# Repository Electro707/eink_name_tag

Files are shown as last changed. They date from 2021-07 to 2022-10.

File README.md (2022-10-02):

# E-Ink Name Tab Project, by Electro707

This project is for a E-Ink name-tag, meant to be the cooler replacement for a paper name-tag for event and shows.

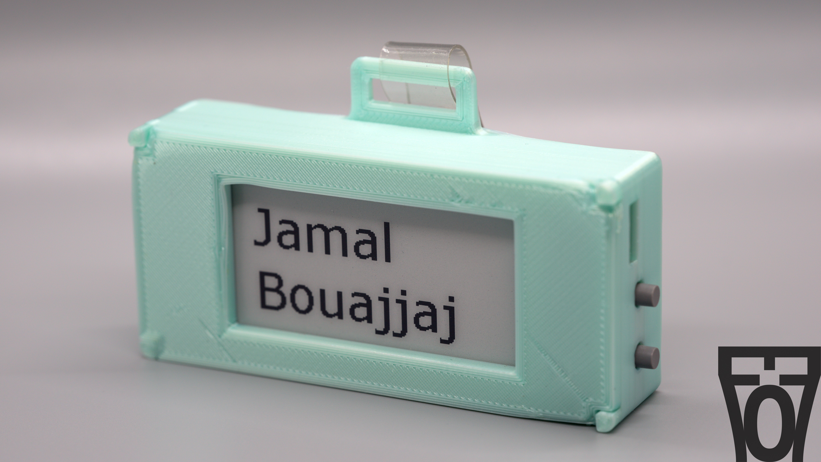
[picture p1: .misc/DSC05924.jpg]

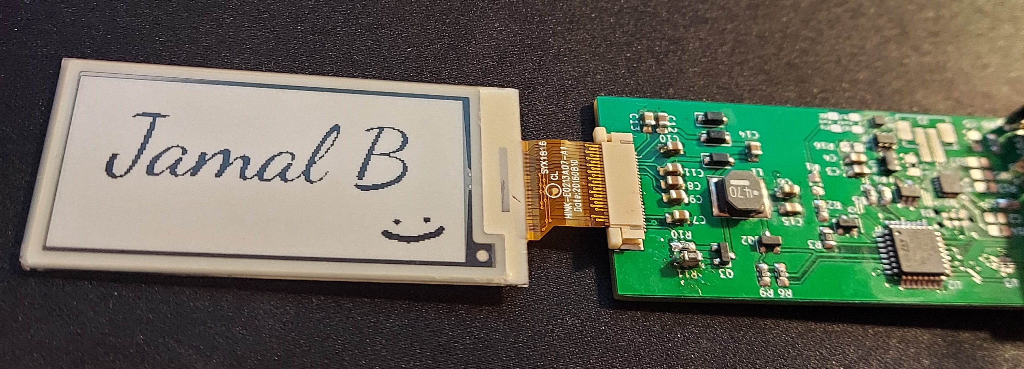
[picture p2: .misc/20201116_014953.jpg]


## Directory

- `STM32CubeIDE`: The firmware created with STM32CubeIDE
- `PCB`: PCB Files made with KiCAD
- `PythonUploader`: A Python GUI and class to communicate with the e-ink tag, mainly to update the "frames"
- `CAD`: Mechanical enclosure made with FreeCAD

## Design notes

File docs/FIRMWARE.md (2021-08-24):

# STM32 Firwamre Overview

## WORK-IN-PROGRESS

## EEPROM Organization

The EEPROM is organized so that the first 32 bytes are used for information like the the number of frames available. The rest of the EEPROM is used to store a frame. Each frame has 44 sections, with each section beign 64 bytes long. 

|Offset|Data|
|---|---|
|0|Info Data *(TODO: Document this)*|
|32|Frame 1's Section 0|
|96|Frame 1's Section 1|
|160|Frame 1's Section 2|
|...|...|
|2784|Frame 1's Section 43|
|2848|Frame 1's Section 44|
|2912|Frame 2's Section 0|
|2976|Frame 2's Section 1|
|...|...|

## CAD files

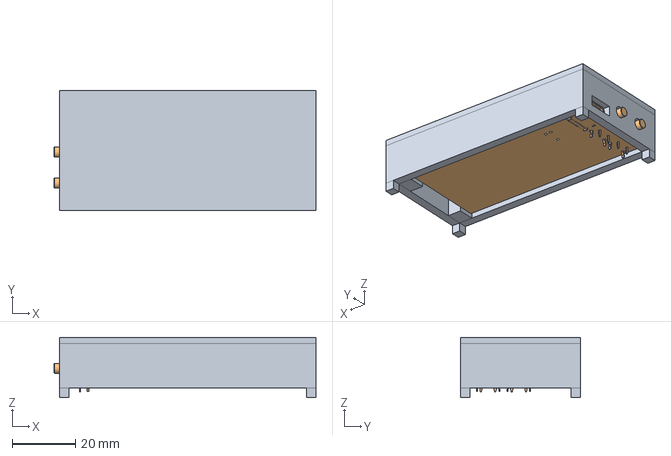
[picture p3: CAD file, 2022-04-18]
CAD/Assembly.FCStd
82.7 x 38.0 x 19.0 mm
T_001
PCB Test1_001

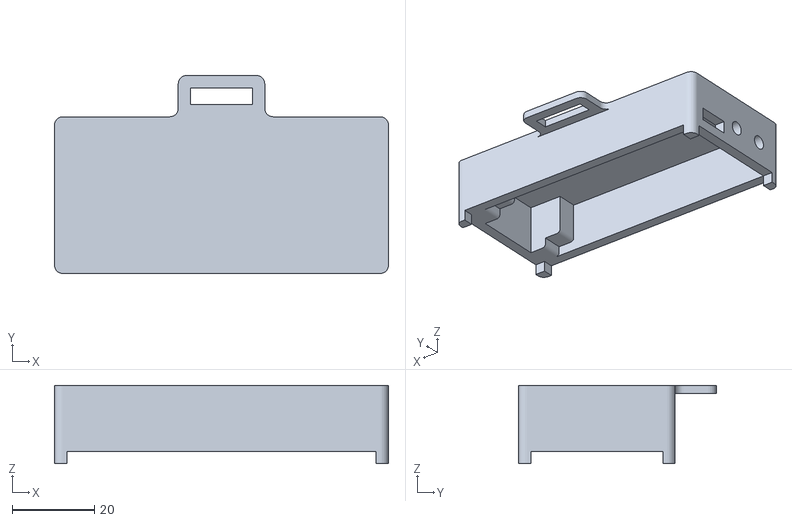
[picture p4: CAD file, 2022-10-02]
CAD/T-Part.stl
81.0 x 48.0 x 19.0

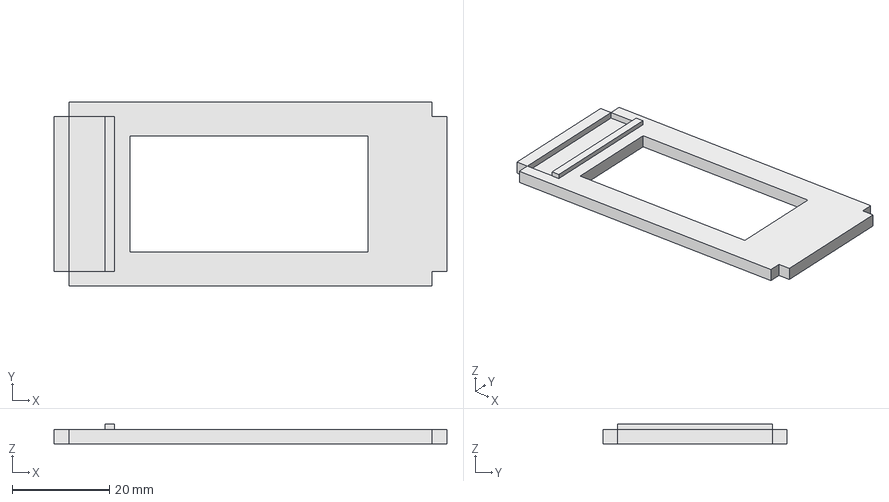
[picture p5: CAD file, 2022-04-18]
CAD/B.FCStd
81.0 x 38.0 x 4.10 mm

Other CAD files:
CAD/T.FCStd

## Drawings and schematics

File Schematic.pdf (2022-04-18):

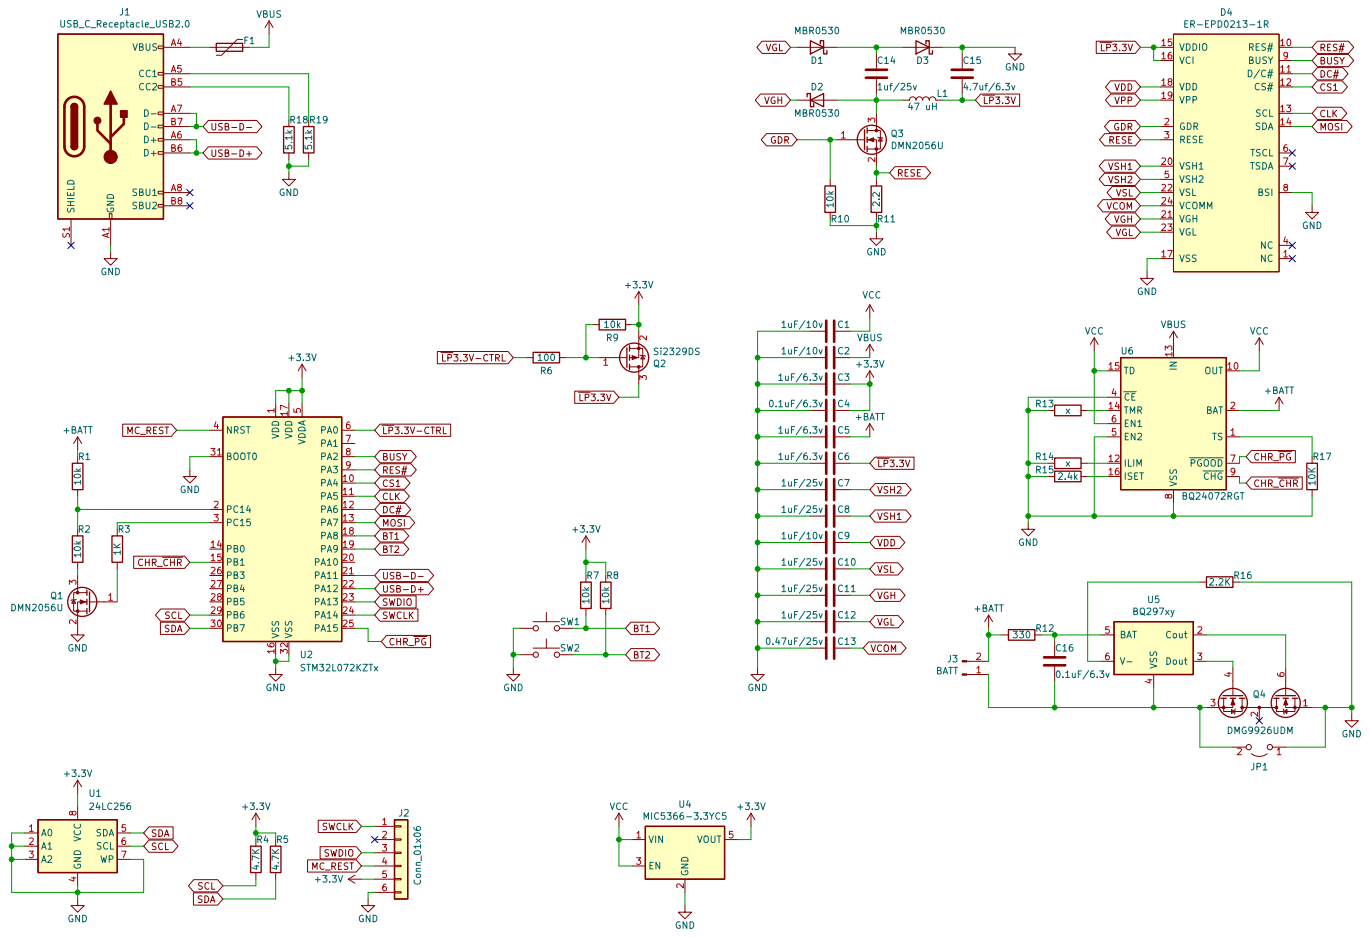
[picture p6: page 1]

RES# ~{LP}3.3V-CTRL SDA

~{LP}3.3V-CTRL SCL SDA

1 PA4 10 PA5 11 PA6 12 PA7 13 PB0 14 PB1 15 VSS 16 VDD 17 PA8 18 PA9 19 PC14 2 PA10 20 PA11 21 PA12 22 PA13 23 PA14 24 PA15 25 PB3 26 PB4 27 PB5 28 PB6 29 PC15 3 PB7 30 BOOT0 31 VSS 32 NRST 4 VDDA

BT2 CS1 SWCLK CLK RES# DC# BT2 MOSI BT1

4 SDA 5 SCL 6 WP 7 VCC

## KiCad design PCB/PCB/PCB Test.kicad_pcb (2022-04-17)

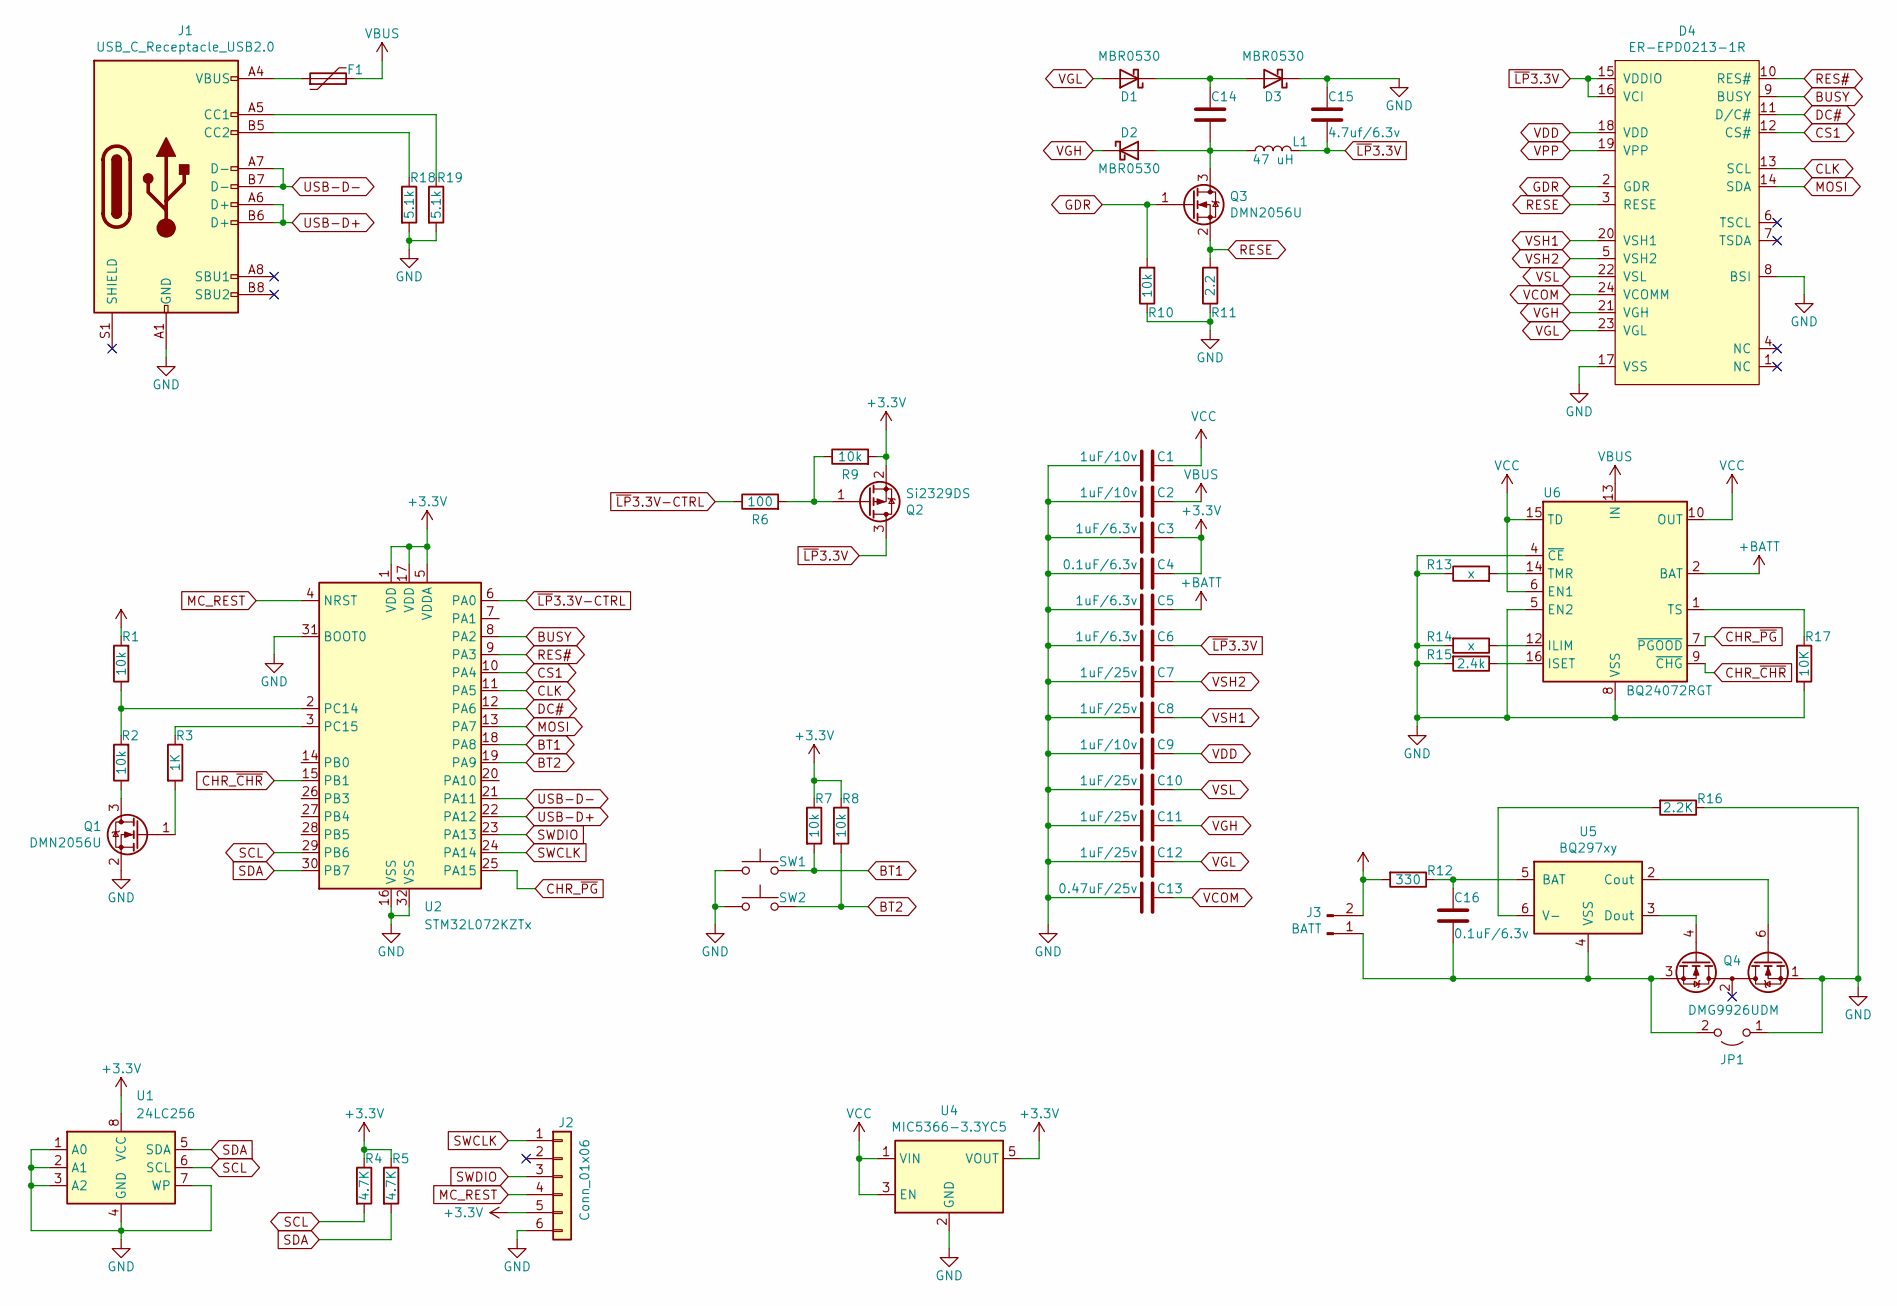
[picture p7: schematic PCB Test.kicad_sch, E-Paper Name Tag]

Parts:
C1, C2, C9: 1uF/10v; C_0805_2012Metric_Pad1.18x1.45mm_HandSolder
C3, C5, C6: 1uF/6.3v; C_0805_2012Metric_Pad1.18x1.45mm_HandSolder
C4, C16: 0.1uF/6.3v; C_0805_2012Metric_Pad1.18x1.45mm_HandSolder
C7, C8, C10, C11, C12: 1uF/25v; C_0805_2012Metric_Pad1.18x1.45mm_HandSolder
C13: 0.47uF/25v; C_0805_2012Metric_Pad1.18x1.45mm_HandSolder
C14: C_0805_2012Metric_Pad1.18x1.45mm_HandSolder
C15: 4.7uf/6.3v; C_0805_2012Metric_Pad1.18x1.45mm_HandSolder
D1, D2, D3: MBR0530; D_SOD-123
D4: ER-EPD0213-1R; TE_2-1734839-4_1x24-1MP_P0.5mm_Horizontal-EINK
F1: Polyfuse; Fuse_1210_3225Metric_Pad1.42x2.65mm_HandSolder
J1: USB_C_Receptacle_USB2.0; USB_C_Receptacle_GCT_USB4085
J2: Conn_01x06; Tag-Connect_TC2030-IDC-NL_2x03_P1.27mm_Vertical
J3: BATT; JST_PH_B2B-PH-SM4-TB_1x02-1MP_P2.00mm_Vertical
JP1: (no value)
L1: 47 uH; L_Taiyo-Yuden_NR-60xx_HandSoldering
Q1, Q3: DMN2056U; SOT-23
Q2: Si2329DS; SOT-23
Q4: DMG9926UDM; SOT-23-6
R1, R2, R7, R8, R9, R10: 10k; R_0805_2012Metric_Pad1.20x1.40mm_HandSolder
R3: 1K; R_0805_2012Metric_Pad1.20x1.40mm_HandSolder
R4, R5: 4.7K; R_0805_2012Metric_Pad1.20x1.40mm_HandSolder
R6: 100; R_0805_2012Metric_Pad1.20x1.40mm_HandSolder
R11: 2.2; R_0805_2012Metric_Pad1.20x1.40mm_HandSolder
R12: 330; R_0805_2012Metric_Pad1.20x1.40mm_HandSolder
R13, R14: x; R_0805_2012Metric_Pad1.20x1.40mm_HandSolder
R15: 2.4k; R_0805_2012Metric_Pad1.20x1.40mm_HandSolder
R16: 2.2K; R_0805_2012Metric_Pad1.20x1.40mm_HandSolder
R17: 10K; R_0805_2012Metric_Pad1.20x1.40mm_HandSolder
R18, R19: 5.1k; R_0805_2012Metric_Pad1.20x1.40mm_HandSolder
SW1, SW2: (no value)
U1: 24LC256; MSOP-8_3x3mm_P0.65mm
U2: STM32L072KZTx; LQFP-32_7x7mm_P0.8mm
U4: MIC5366-3.3YC5; SOT-353_SC-70-5
U5: BQ297xy; WSON-6_1.5x1.5mm_P0.5mm
U6: BQ24072RGT; VQFN-16-1EP_3x3mm_P0.5mm_EP1.6x1.6mm

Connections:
+3V3: C3.1, C4.1, J2.5, Q2.2 (S), R4.1, R5.1, R7.1, R8.1, R9.2, U1.8 (VCC), U2.1 (VDD), U2.5 (VDDA), U2.17 (VDD), U4.5 (VOUT)
BT1: R7.2, SW1.2, U2.18 (PA8)
BT2: R8.2, SW2.2, U2.19 (PA9)
BUSY: D4.9 (BUSY), U2.8 (PA2)
CHR_~CHR: U2.15 (PB1), U6.9 (~CHG)
CHR_~PG: U2.25 (PA15), U6.7 (~PGOOD)
CLK: D4.13 (SCL), U2.11 (PA5)
CS1: D4.12 (CS#), U2.10 (PA4)
DC#: D4.11 (D/C#), U2.12 (PA6)
GDR: D4.2 (GDR), Q3.1 (G), R10.2
GND: C1.2, C2.2, C3.2, C4.2, C5.2, C6.2, C7.2, C8.2, C9.2, C10.2, C11.2, C12.2, C13.2, C15.1, D3.1 (K), D4.8 (BSI), D4.17 (VSS), J1.A1 (GND), J1.A12 (GND), J1.B1 (GND), J1.B12 (GND), J2.6, JP1.1 (A), Q1.2 (S), Q4.1 (D1), R10.1, R11.1, R13.1, R14.2, R15.2, R16.1, R17.2, R18.2, R19.2, SW1.1, SW2.1, U1.1 (A0), U1.2 (A1), U1.3 (A2), U1.4 (GND), U1.7 (WP), U2.16 (VSS), U2.31 (BOOT0), U2.32 (VSS), U4.2 (GND), U6.4 (~CE), U6.5 (EN2), U6.8 (VSS), U6.17 (VSS)
MC_REST: J2.4, U2.4 (NRST)
MOSI: D4.14 (SDA), U2.13 (PA7)
unnamed: C14.1, D1.1 (K), D3.2 (A)
unnamed: C14.2, D2.2 (A), L1.1, Q3.3 (D)
unnamed: C16.1, R12.1, U5.5 (BAT)
unnamed: C16.2, J3.1, JP1.2 (B), Q4.3 (S2), U5.4 (VSS)
unnamed: F1.1, J1.A4 (VBUS), J1.A9 (VBUS), J1.B4 (VBUS), J1.B9 (VBUS)
unnamed: J1.A5 (CC1), R19.1
unnamed: J1.B5 (CC2), R18.1
unnamed: Q1.1 (G), R3.2
unnamed: Q1.3 (D), R2.1
unnamed: Q2.1 (G), R6.2, R9.1
unnamed: Q4.4 (G2), U5.3 (Dout)
unnamed: Q4.6 (G1), U5.2 (Cout)
unnamed: R13.2, U6.14 (TMR)
unnamed: R14.1, U6.12 (ILIM)
unnamed: R15.1, U6.16 (ISET)
unnamed: R16.2, U5.6 (V-)
unnamed: R17.1, U6.1 (TS)
unnamed: R1.1, R2.2, U2.2 (PC14)
unnamed: R3.1, U2.3 (PC15)
RES#: D4.10 (RES#), U2.9 (PA3)
RESE: D4.3 (RESE), Q3.2 (S), R11.2
SCL: R4.2, U1.6 (SCL), U2.29 (PB6)
SDA: R5.2, U1.5 (SDA), U2.30 (PB7)
SWCLK: J2.1, U2.24 (PA14)
SWDIO: J2.3, U2.23 (PA13)
USB-D+: J1.A6 (D+), J1.B6 (D+), U2.22 (PA12)
USB-D-: J1.A7 (D-), J1.B7 (D-), U2.21 (PA11)
VBUS: C2.1, F1.2, U6.13 (IN)
VCC: C1.1, U4.1 (VIN), U4.3 (EN), U6.6 (EN1), U6.10 (OUT), U6.11 (OUT), U6.15 (TD)
VCOM: C13.1, D4.24 (VCOMM)
VDD: C9.1, D4.18 (VDD)
VGH: C11.1, D2.1 (K), D4.21 (VGH)
VGL: C12.1, D1.2 (A), D4.23 (VGL)
VPP: D4.19 (VPP)
VSH1: C8.1, D4.20 (VSH1)
VSH2: C7.1, D4.5 (VSH2)
VSL: C10.1, D4.22 (VSL)
~LP3.3V: C6.1, C15.2, D4.15 (VDDIO), D4.16 (VCI), L1.2, Q2.3 (D)
~LP3.3V-CTRL: R6.1, U2.6 (PA0)

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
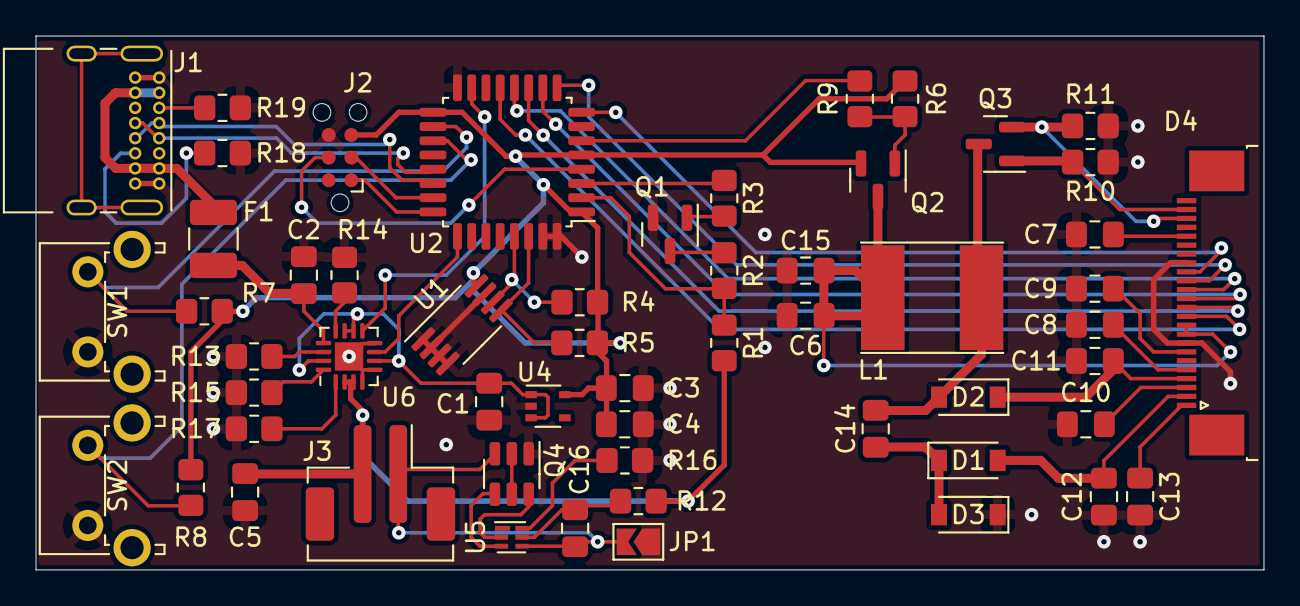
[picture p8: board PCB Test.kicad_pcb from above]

Board: 2 copper layers, 69.0 x 30.0 mm, 56 parts (0 on the bottom side), 52 nets.

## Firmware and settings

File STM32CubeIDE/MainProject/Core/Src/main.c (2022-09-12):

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
/* Includes ------------------------------------------------------------------*/
#include "main.h"
#include "usb_device.h"

/* USER CODE BEGIN Includes */
#include "usbd_cdc_if.h"
#include "paper.h"
#include "24FC64F.h"
#define DISPLAY_ON POWER_SWITCH_GPIO_Port->ODR &= ~(POWER_SWITCH_Pin)
#define DISPLAY_OFF POWER_SWITCH_GPIO_Port->ODR |= (POWER_SWITCH_Pin)

// The section size is really dependent on USB CDC's write capabilities which is best done
// 64 bytes at a time
#define SECTION_SIZE 64
// The numbmer of "sections" to make up a single frame, in this case (64*44) = 22528 bits.
// The display has 212*104=22048 bits
#define SECTION_PER_FRAME 44
#define BYTES_PER_FRAME SECTION_SIZE * SECTION_PER_FRAME
// A section from the start of the EEPROM reserved for user settings.
// This should be a multiple of 32 due to the EEPROM's page write size
#define EEPROM_USER_SETTING_SIZE 32

uint8_t current_frame = 0;
uint8_t display_buffer[BYTES_PER_FRAME];
uint8_t version_string[] = "Epaper Rev C\n";


int usb_asking_numb_data = 0;
uint8_t usb_asking_for = 0;
uint8_t ee_write_frame = 0;
uint8_t ee_write_section = 0;

uint8_t handle_loop_extra_stuff = 0;
uint8_t handle_main_loop = 0;

void handle_usb_packet(void);
void handle_usb_extra_data(void);
/* USER CODE END Includes */

/* USER CODE BEGIN PTD */
UserSettings_t user_settings = {
	.numb_of_frames = 3,
};
/* USER CODE END PTD */


void SystemClock_Config(void);
static void MX_GPIO_Init(void);
static void MX_CRC_Init(void);
static void MX_I2C1_Init(void);
static void MX_SPI1_Init(void);
/**
  * @brief  The application entry point.
  * @retval int
  */
int main(void)
{
  /* MCU Configuration--------------------------------------------------------*/

  /* Reset of all peripherals, Initializes the Flash interface and the Systick. */
  HAL_Init();

  /* Configure the system clock */
  SystemClock_Config();

  /* Initialize all configured peripherals */
  MX_GPIO_Init();
  MX_CRC_Init();
  MX_I2C1_Init();
  MX_SPI1_Init();
  MX_USB_DEVICE_Init();
  /* USER CODE BEGIN 2 */
//  get_setting_from_ee();
  DISPLAY_ON;
  LL_SPI_Enable(SPI1);
  Paper_Init();
  Paper_Clear(); Paper_TurnOnDisplay();
  Paper_Sleep();
  DISPLAY_OFF;
  /* USER CODE END 2 */

  /* Infinite loop */
  /* USER CODE BEGIN WHILE */
  while (1)
  {
    if(handle_loop_extra_stuff == 1){
	  NVIC_DisableIRQ(USB_IRQn);
	  handle_usb_extra_data();
	  NVIC_EnableIRQ(USB_IRQn);
	  handle_loop_extra_stuff = 0;
	}
	else if(handle_loop_extra_stuff == 2){
	  NVIC_DisableIRQ(USB_IRQn);
	  display_frame_number(ee_write_frame);
	  NVIC_EnableIRQ(USB_IRQn);
	  handle_loop_extra_stuff = 0;
	}

	if(handle_main_loop == 1){
	  NVIC_DisableIRQ(USB_IRQn);
	  handle_usb_packet();
	  NVIC_EnableIRQ(USB_IRQn);
	  handle_main_loop = 0;
	}
    /* USER CODE END WHILE */

    /* USER CODE BEGIN 3 */
  }
  /* USER CODE END 3 */
}

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
/* USER CODE BEGIN 4 */
/**
 * Function that gets settings stored in EEPROM, such as the nummber of
 */
void get_setting_from_ee(){
	uint8_t ee_user_data[EEPROM_USER_SETTING_SIZE];
	ee24fc64_multi_read_read(ee_user_data, EEPROM_USER_SETTING_SIZE, 0);
	user_settings.numb_of_frames = ee_user_data[0];
}

void store_settings_to_ee(){
	uint8_t ee_user_data[EEPROM_USER_SETTING_SIZE];
	memset(ee_user_data, 0, EEPROM_USER_SETTING_SIZE);	// Making sure the user data written starts out empty
	ee_user_data[0] = user_settings.numb_of_frames;

	uint16_t start_address = 0;
	for(int i=0;i<EEPROM_USER_SETTING_SIZE/32;i++){
		ee24fc64_multi_write(&UserRxBufferFS[(32*i)], 32, start_address);
		start_address += 32;
	}
}

void display_frame_number(uint8_t frame_number){
	uint16_t start_address = frame_number*BYTES_PER_FRAME + EEPROM_USER_SETTING_SIZE;
	for(int i=0;i<SECTION_PER_FRAME;i++){
		ee24fc64_multi_read_read(&display_buffer[i*SECTION_SIZE], SECTION_SIZE, start_address);
		start_address += SECTION_SIZE;
	}
	DISPLAY_ON; Paper_Init();
	Paper_Display(display_buffer);
	Paper_Sleep();
	DISPLAY_OFF;
}


void handle_usb_packet(){
	uint8_t frame, section;
	uint16_t start_address;
	if(UserRxBufferFS[0] == 0x02){
		ee_write_frame = UserRxBufferFS[1];
		ee_write_section = UserRxBufferFS[2];
		usb_asking_for = 1;
		usb_asking_numb_data = SECTION_SIZE;
		UserTxBufferFS[0] = 0xFE; UserTxBufferFS[1] = '\n';
		CDC_Transmit_FS(UserTxBufferFS, 2);
	}
	else if(UserRxBufferFS[0] == 0x03){
		frame = UserRxBufferFS[1];
		section = UserRxBufferFS[2];
		start_address = (frame*BYTES_PER_FRAME) + (section*SECTION_SIZE) + EEPROM_USER_SETTING_SIZE;
		memset(&UserTxBufferFS[0], 0, SECTION_SIZE);
		ee24fc64_multi_read_read(&UserTxBufferFS[0], SECTION_SIZE, start_address);
		CDC_Transmit_FS(UserTxBufferFS, SECTION_SIZE);
	} else if(UserRxBufferFS[0] == 'v'){
		CDC_Transmit_FS(version_string, sizeof(version_string)-1);
	} else if(UserRxBufferFS[0] == 0x20){
		ee_write_frame = UserRxBufferFS[1];
		handle_loop_extra_stuff = 2;
	}
}

void handle_usb_extra_data(){
	uint32_t crc; uint16_t start_address;
	if(usb_asking_for == 1){
		LL_CRC_SetInitialData(CRC, 0);
		start_address = (ee_write_frame*BYTES_PER_FRAME) + (ee_write_section*SECTION_SIZE) + EEPROM_USER_SETTING_SIZE;
		for(int i=0;i<SECTION_SIZE/32;i++){
			ee24fc64_multi_write(&UserRxBufferFS[(32*i)], 32, start_address);
			for(int f=0;f<32;f++){LL_CRC_FeedData8(CRC, UserRxBufferFS[(32*i)+f]);}
			start_address += 32;
		}
		crc = LL_CRC_ReadData32(CRC);
		crc = ~crc;
		memcpy(&UserTxBufferFS[0], &crc, 4); UserTxBufferFS[4] = '\n';
		CDC_Transmit_FS(UserTxBufferFS, 5);
	}
	usb_asking_for = 0;
	usb_asking_numb_data = 0;
}

/* USER CODE END 4 */
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


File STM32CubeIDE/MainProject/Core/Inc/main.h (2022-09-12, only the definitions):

#define POWER_SWITCH_Pin LL_GPIO_PIN_0
#define POWER_SWITCH_GPIO_Port GPIOA
#define EPAPER_BUSY_Pin LL_GPIO_PIN_2
#define EPAPER_BUSY_GPIO_Port GPIOA
#define EPAPER_RST_Pin LL_GPIO_PIN_3
#define EPAPER_RST_GPIO_Port GPIOA
#define EPAPER_CS_Pin LL_GPIO_PIN_4
#define EPAPER_CS_GPIO_Port GPIOA
#define EPAPER_DC_Pin LL_GPIO_PIN_6
#define EPAPER_DC_GPIO_Port GPIOA
#define BUTTON1_Pin LL_GPIO_PIN_8
#define BUTTON1_GPIO_Port GPIOA
#define BUTTON1_EXTI_IRQn EXTI4_15_IRQn
#define BUTTON2_Pin LL_GPIO_PIN_9
#define BUTTON2_GPIO_Port GPIOA
#define BUTTON2_EXTI_IRQn EXTI4_15_IRQn

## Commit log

2021-07-15 Initial Release
    [PCB Test.kicad_pcb, PCB Test.kicad_sch, PCB Test.sch]
2021-08-23 Added more code docs. Started switching flags to ENUMs
2021-08-24 Added option to set max frames. Lots of Python GUI refractoring
2021-08-25 Removed older schematic file
    [PCB Test.sch]
2022-04-17 Updated schematic to Rev C
    [PCB Test.kicad_pcb, PCB Test.kicad_sch]
2022-04-17 Updated firmware for RevC of the PCB
2022-04-18 Added CAD models. Updated Python scipt. Added shematic
    [Assembly.FCStd, B.FCStd, T.FCStd]
2022-09-12 Updated CAD model to include a lanyard slot. Changes with code described below:
    Added a user settings allocation in the EEPROM, for example for the number of available frames
    Added more comments to code
    Fixed bug where pressing the button while the display is updated will cause another updated. Also serves as a cheap "debouncing"
    [T.FCStd]
2022-10-02 Added new picture
    [T-Part.stl]

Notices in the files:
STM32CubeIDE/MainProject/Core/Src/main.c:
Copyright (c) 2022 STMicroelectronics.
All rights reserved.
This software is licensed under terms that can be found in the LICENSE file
